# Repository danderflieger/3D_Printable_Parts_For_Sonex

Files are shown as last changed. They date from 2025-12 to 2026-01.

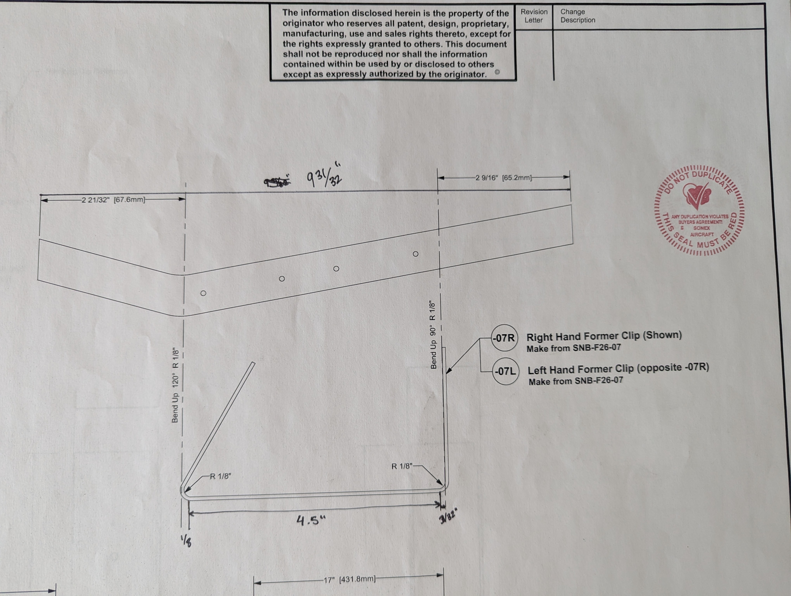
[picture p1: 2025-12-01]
Former Clip Bending Template/PXL_20250518_170153234~2.jpg

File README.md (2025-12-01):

# 3D Printable Parts for Sonex
This repository is where I will keep (and share) 3D modeled parts for my Sonex model B aircraft kit. In some cases, they are parts that can be 3D printed and used directly with my Sonex. In other cases, they are 3D printable tools or fixtures that I used while building my Sonex. Seems like a shame to keep them for myself.

## If you decide to use anything here, you do so at your own risk. I'm building an experimental ameteur built aircraft and these parts are very much on the experimental side.

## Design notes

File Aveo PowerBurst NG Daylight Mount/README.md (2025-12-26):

# Aveo PowerBurst NG Daylight Wing-end Light Mounts

This project contains 3D printable parts designed in Solid Edge that allow you to connect the Aveo PowerBurst NG Daylight wing end position/strobe lights to a Sonex wingend. The Sonex wingend rib is set at 45° and the lights needs a 45° offset mount for the lights to point directly outward (as opposed to 45° downward).

There are two ways to make the light mounts:
- you can 3D print the mount and use it straight off the 3D printer
- you can 3D print a 2-piece mold and lay up either fiberglass or carbon fiber with a 2-part resin. 

In either case, I have included the .par (Solid Edge part) and STL files in this repository. 

## 3D printed part
  Location: Aveo PowerBurst NG Daylight Mount/3D Printable

In the case of direcly using a printed part, be sure to print it in a material that can withstand the elements. PLA is plant based and will deteriorate outdoors. Additionally, it's not very heat resistant, so the part is likely to reach its "glassing" temerature on a hot summer day. When a 3D printable filament reaches its glassing temperature, wil begins to become soft and will no longer hold its shape. I suggest ABS or ASA filament for this project. Even better, a carbon fiber (CF) infused ABS or ASA filament. The CF particles do not grow/shrink with temperature change and your part is more likely to hold its shape.

I have added STL files for these 3D models: __Aveo PowerBurst NG Daylight Mount/3D Printable/STL Files/__

## 3D printed mold for compsite lay-up
  Location: Aveo PowerBurst NG Daylight Mount/Composite Molds

I have prepared a second option for those interested in laying up a composite material. I changed the part to have a slight "draft" (a bevel that allows the part to be easily removed from a mold). This option has three Solid Edge part files:

- __Aveo PowerBurst NG Daylite Mount-With-Draft.par__ - this file is the new part with the draft. The dimmensions are the same as the 3D printable part on the side where the light is affixed. However, with the draft, the side that butts up against the wingend rib is slightly larger as it follows the draft. This part can be printed and used to make a mold out of composites material (or printed and used as-is, like the option above). 
- __Aveo PowerBurst NG Daylite Mount-Mold-Cavity.par__ - This is the concave portion of the mold that can be 3D printed.
- __Aveo PowerBurst NG Daylite Mount-Mold-Core.par__ - This is the convex portion of the mold that can be 3D printed.

I have added STL files for these 3D models: __Aveo PowerBurst NG Daylight Mount/Composite Molds/STL Files__

Note: I used Solid Edge to determine that the volume of the drafted part is  31.343 cm^3. I suggest using:
- <del>21.2</del> 25 grams of carbon fiber
- <del>14.2</del> 20 grams of resin

I came to these values by watching [this video](https://www.youtube.com/watch?v=nhqAhYOdGNc&t=12m24s). I suggest watching the entire video - it's very enlightening. 

Here are my calculations base on the numbers provided in the video:
23.572 cm^3 (part volume) x 1.5 grams of carbon fiber + resin (by weight) per cm^3 = 35.358 grams of carbon fiber + resin
Of that total, we want to use 60% carbon fiber (by weight) and 40% resin (by weight). So ...
- 35.358 grams x 60% = 21.2148 grams of carbon fiber (rounded to 21.2 grams)
- 35.358 grams x 40% = 14.1432 grams of resin (rounded to 14.2 grams)

OLD VALUES - Before updated model with more draft an thinner walls:

<del>31.434 cm^3 (part volume) x 1.4 grams of carbon fiber and resin per cm^3 of volume = 44.0076 grams of carbon fiber + resin
Of that total, we want to use 60% carbon fiber (by weight) and 40% resin (by weight). So ... </del>
- <del>44.0076 grams x 60% (0.60) = 26.40456 grams of carbon fiber (rounded to 26.4 grams)</del>
- <del>44.0076 grams x 40% (0.40) = 17.60304 grams of resin (rounded to 17.6 grams)</del>

## 3D Print Settings
I elected to print my parts using PETG-CF filament, .2mm layers, 3mm walls, 3mm top/bottom, with 50% infill. I over-estimated the amount of strength needed for all of the printed parts. On my upgraded Creality Ender3 printer, the Cavity took 11 hours to print and the Core took about 13 hours. Remember that you will also need to print both of those parts mirrored to make the mount for the left wing. I didn't model a separate part, just mirror the STL files in your slicing software before printing them.

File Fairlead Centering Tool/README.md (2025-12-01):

# Fairlead Centering Tool
This is a very simple fixture that can be used to center your rudder cable fairlead assembly in the vertical upright where it goes. 

 

 



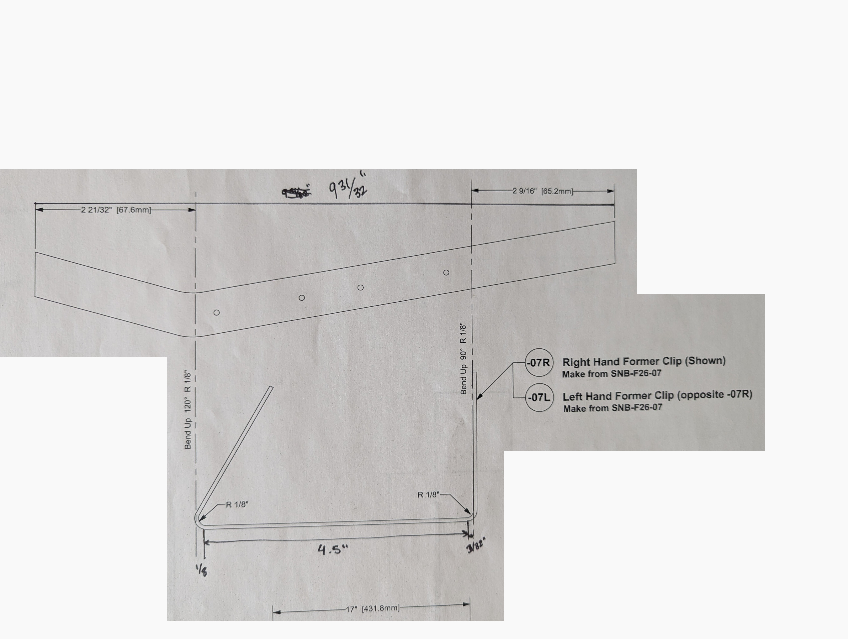
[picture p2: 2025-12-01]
Former Clip Bending Template/Edited_Photo.jpg

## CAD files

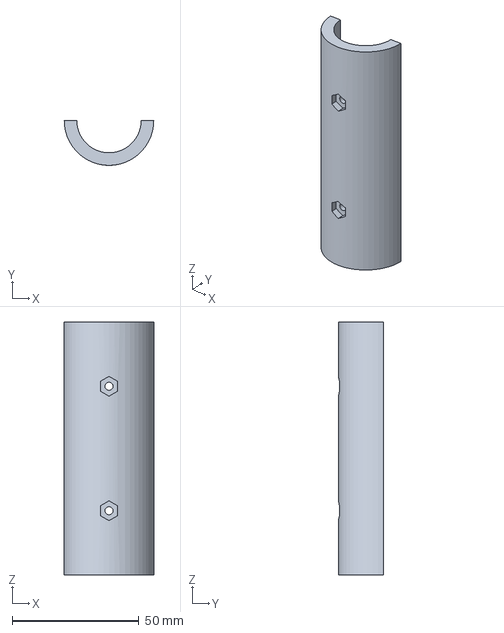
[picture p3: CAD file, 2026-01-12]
Control Stick Grip/Vertical_Grip_Rear_Main.FCStd
35.4 x 17.7 x 100.0 mm

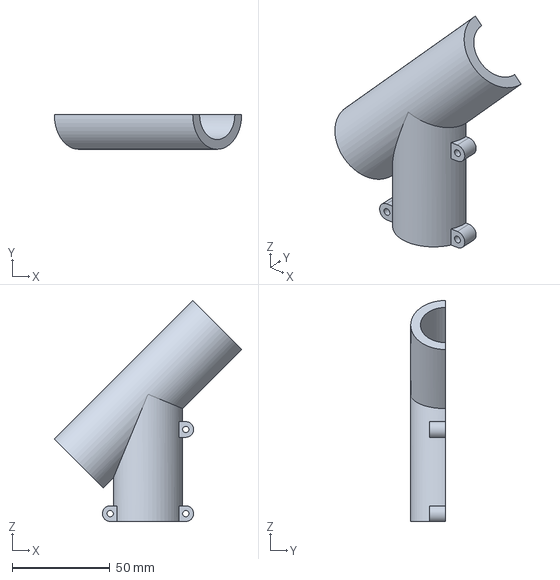
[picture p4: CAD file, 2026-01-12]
Control Stick Grip/Angled_Grip_Rear_Main.FCStd
95.7 x 17.7 x 112.9 mm

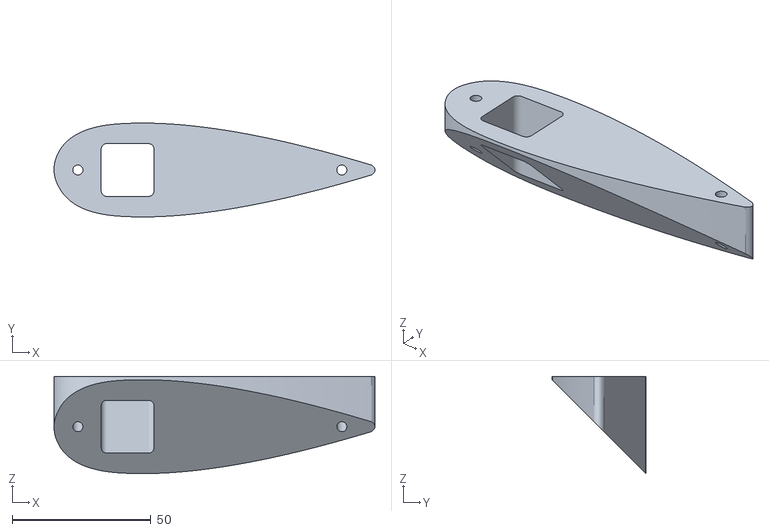
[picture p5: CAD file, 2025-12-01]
Aveo PowerBurst NG Daylight Mount/3D Printable/STL Files/Aveo PowerBurst NG Daylite Mount-Right.stl
115.5 x 33.8 x 35.0

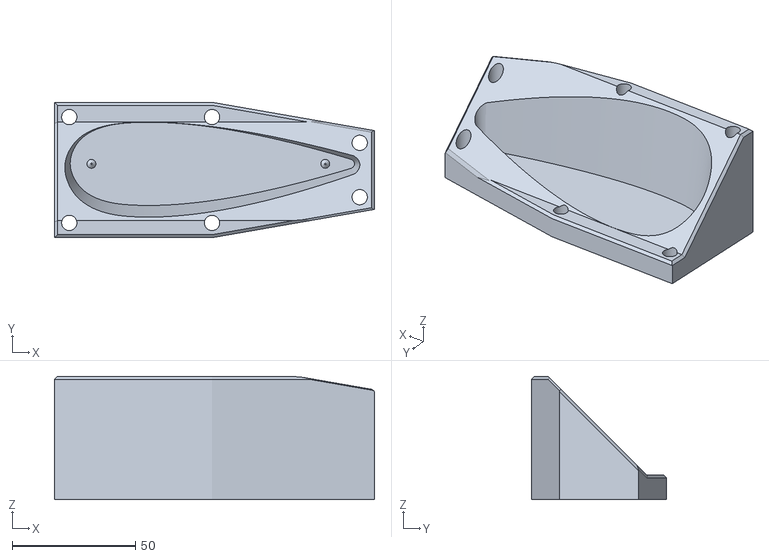
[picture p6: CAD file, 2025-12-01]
Aveo PowerBurst NG Daylight Mount/Composite Molds/STL Files/Aveo PowerBurst NG Daylite Mount-Mold-Cavity.stl
130.0 x 55.0 x 50.0

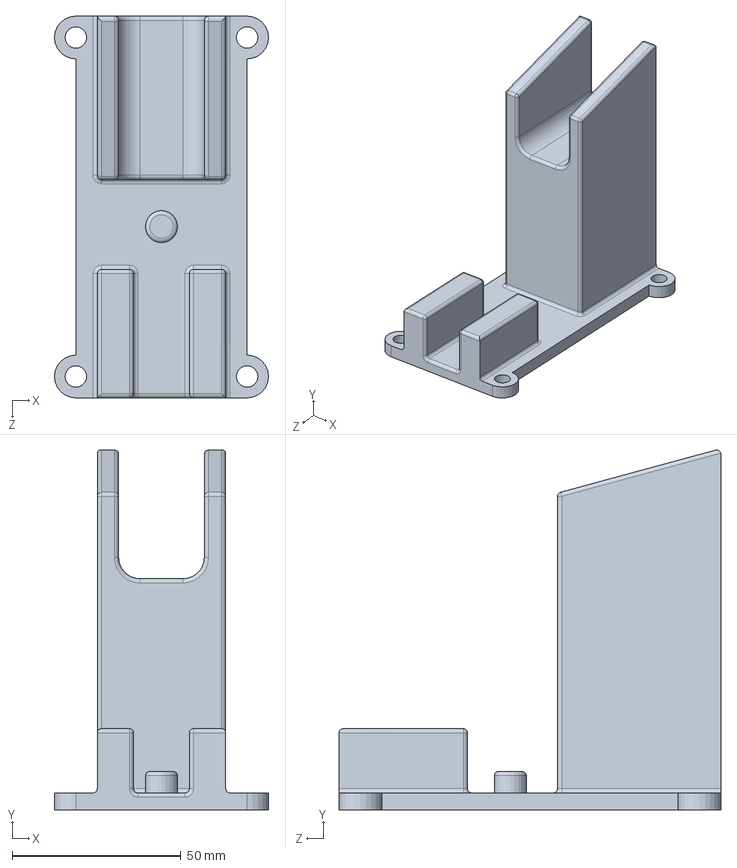
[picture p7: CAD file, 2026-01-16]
Control Stick Alignment Fixture/Control Stick Alignment Fixture.SLDPRT
63.5 x 106.8 x 113.2 mm

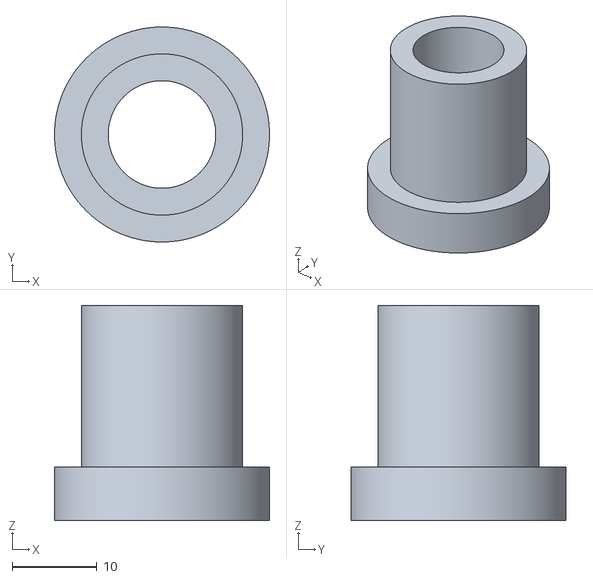
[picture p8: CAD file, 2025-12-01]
Fairlead Centering Tool/Fairlead Centering Tool.stl
25.4 x 25.4 x 25.4

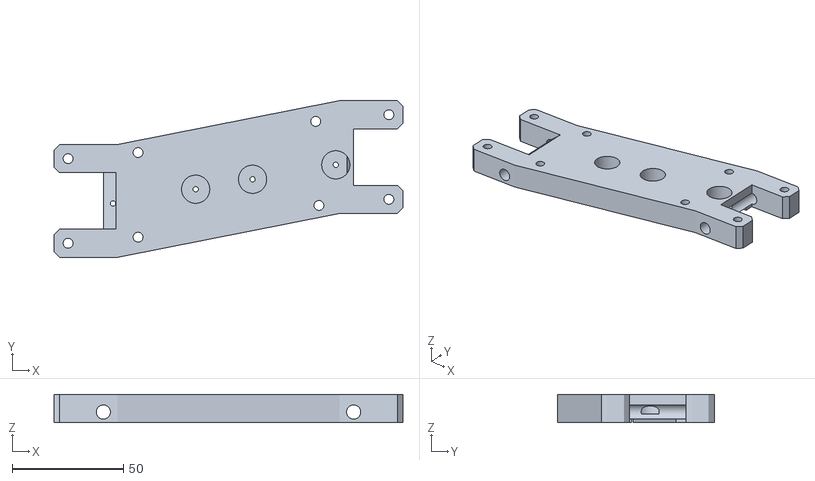
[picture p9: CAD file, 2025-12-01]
Former Clip Bending Template/STL Files/Former Clip Bending Template.stl
157.2 x 70.6 x 12.7

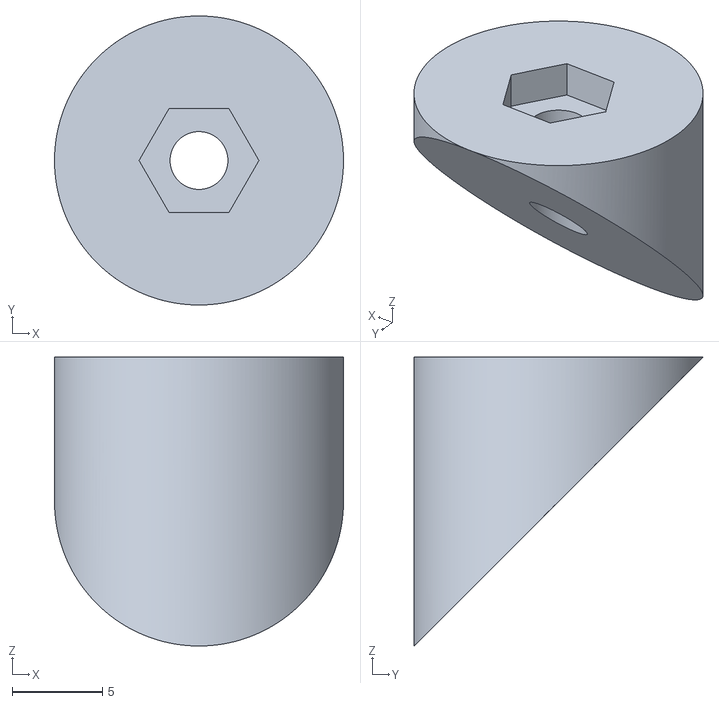
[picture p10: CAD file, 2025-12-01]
Aveo PowerBurst NG Daylight Mount/3D Printable/STL Files/Aveo PowerBurst NG Daylite Rear Stand-off.stl
16.0 x 16.0 x 16.0

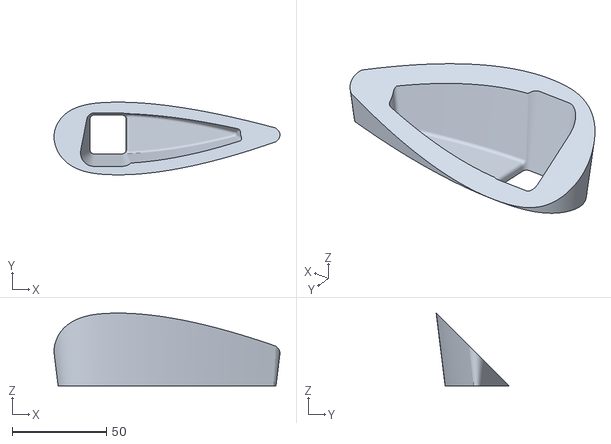
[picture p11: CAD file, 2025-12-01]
Aveo PowerBurst NG Daylight Mount/Composite Molds/STL Files/Aveo PowerBurst NG Daylite Mount-With-Draft.stl
119.8 x 38.5 x 38.6

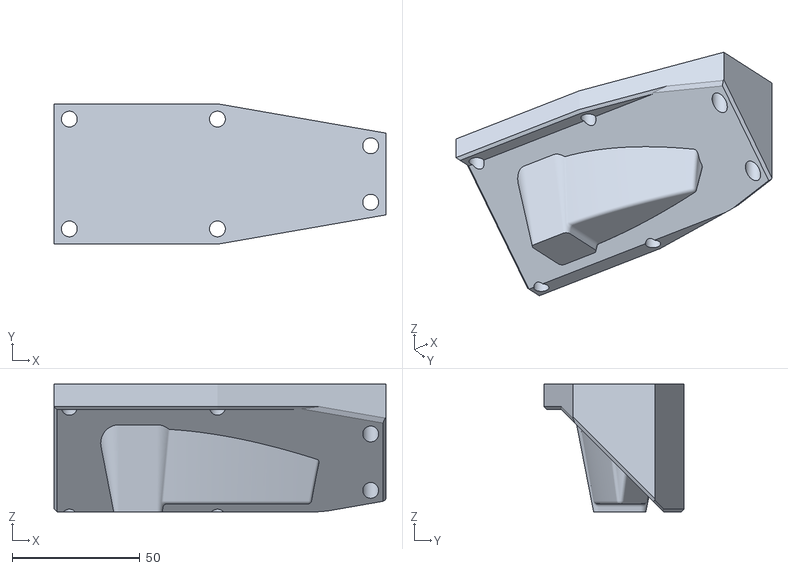
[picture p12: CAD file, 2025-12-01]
Aveo PowerBurst NG Daylight Mount/Composite Molds/STL Files/Aveo PowerBurst NG Daylite Mount-Mold-Core.stl
130.0 x 55.0 x 50.0

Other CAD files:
Control Stick Alignment Fixture/Control Stick Alignment Fixture.STL

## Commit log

2026-01-09 Started playing around with FreeCAD. Started drafting a custom control stick grip to learn. FreeCAD 1.0.x seems to be decent (older versions weren't as good), but there's always a learning curve ... 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
    [Grip_Rear_Lower.FCStd]
2026-01-12 Decided to simplify the control stick a little and make another copy of one that is vertical instead of at a 45 degree angle.
    [Angled_Grip_Rear_Main.FCStd, Grip_Rear_Lower.FCStd, Vertical_Grip_Rear_Main.FCStd]
2026-01-16 Added the fixture to line up the two control sticks to the control horns for a dual stick upgrade.
    [Control Stick Fixture.SLDPRT, Control Stick Fixture.STL]
2026-01-16 Renamed the directory to "Control Stick Alignment Fixture" to make its purpose more clear.
    [Control Stick Fixture.SLDPRT, Control Stick Fixture.STL]
2026-01-16 Changed the name of the files to make the purpose more clear.
    [Control Stick Alignment Fixture.SLDPRT, Control Stick Alignment Fixture.STL]
